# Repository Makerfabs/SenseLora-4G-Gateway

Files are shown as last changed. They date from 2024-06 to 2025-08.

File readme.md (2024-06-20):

# SenseLoRa 4G Gateway

```c++
/*
Version:		V1.0
Author:			Vincent
Create Date:	2024/6/19
Note:

*/
```
# Makerfabs

[Makerfabs home page](https://www.makerfabs.com/)

[Makerfabs Wiki](https://wiki.makerfabs.com/)

# How To Use

## Arduino Complier Option

**If you have any questions，such as how to install the development board, how to download the code, how to install the library. Please refer to :[Makerfabs_FAQ](https://github.com/Makerfabs/Makerfabs_FAQ)**

- Install board : ESP32 Version 2.0.11
- Select "ESP32-S3"
- Select Erase All Flash
- Upload codes

Arduino libraries:

- RadioLib 4.6.0

## Example

### fw_test

The factory test program detects whether the AT module can search for the operator and receives Lora data in a loop.

### at_test

Used to debug the AT module and perform transparent serial port transmission.

### lora2thingspeak

The JSON data from the SenseLora Air Monitor is parsed and forwarded to ThingSpeak.

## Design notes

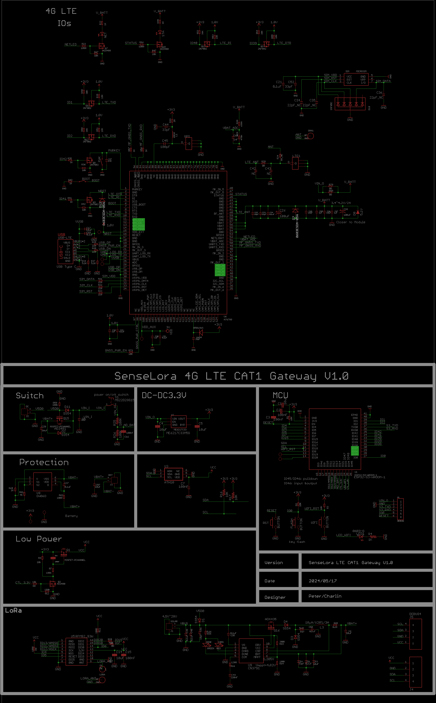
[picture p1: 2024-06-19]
hardware/SenseLora 4G Gateway.png

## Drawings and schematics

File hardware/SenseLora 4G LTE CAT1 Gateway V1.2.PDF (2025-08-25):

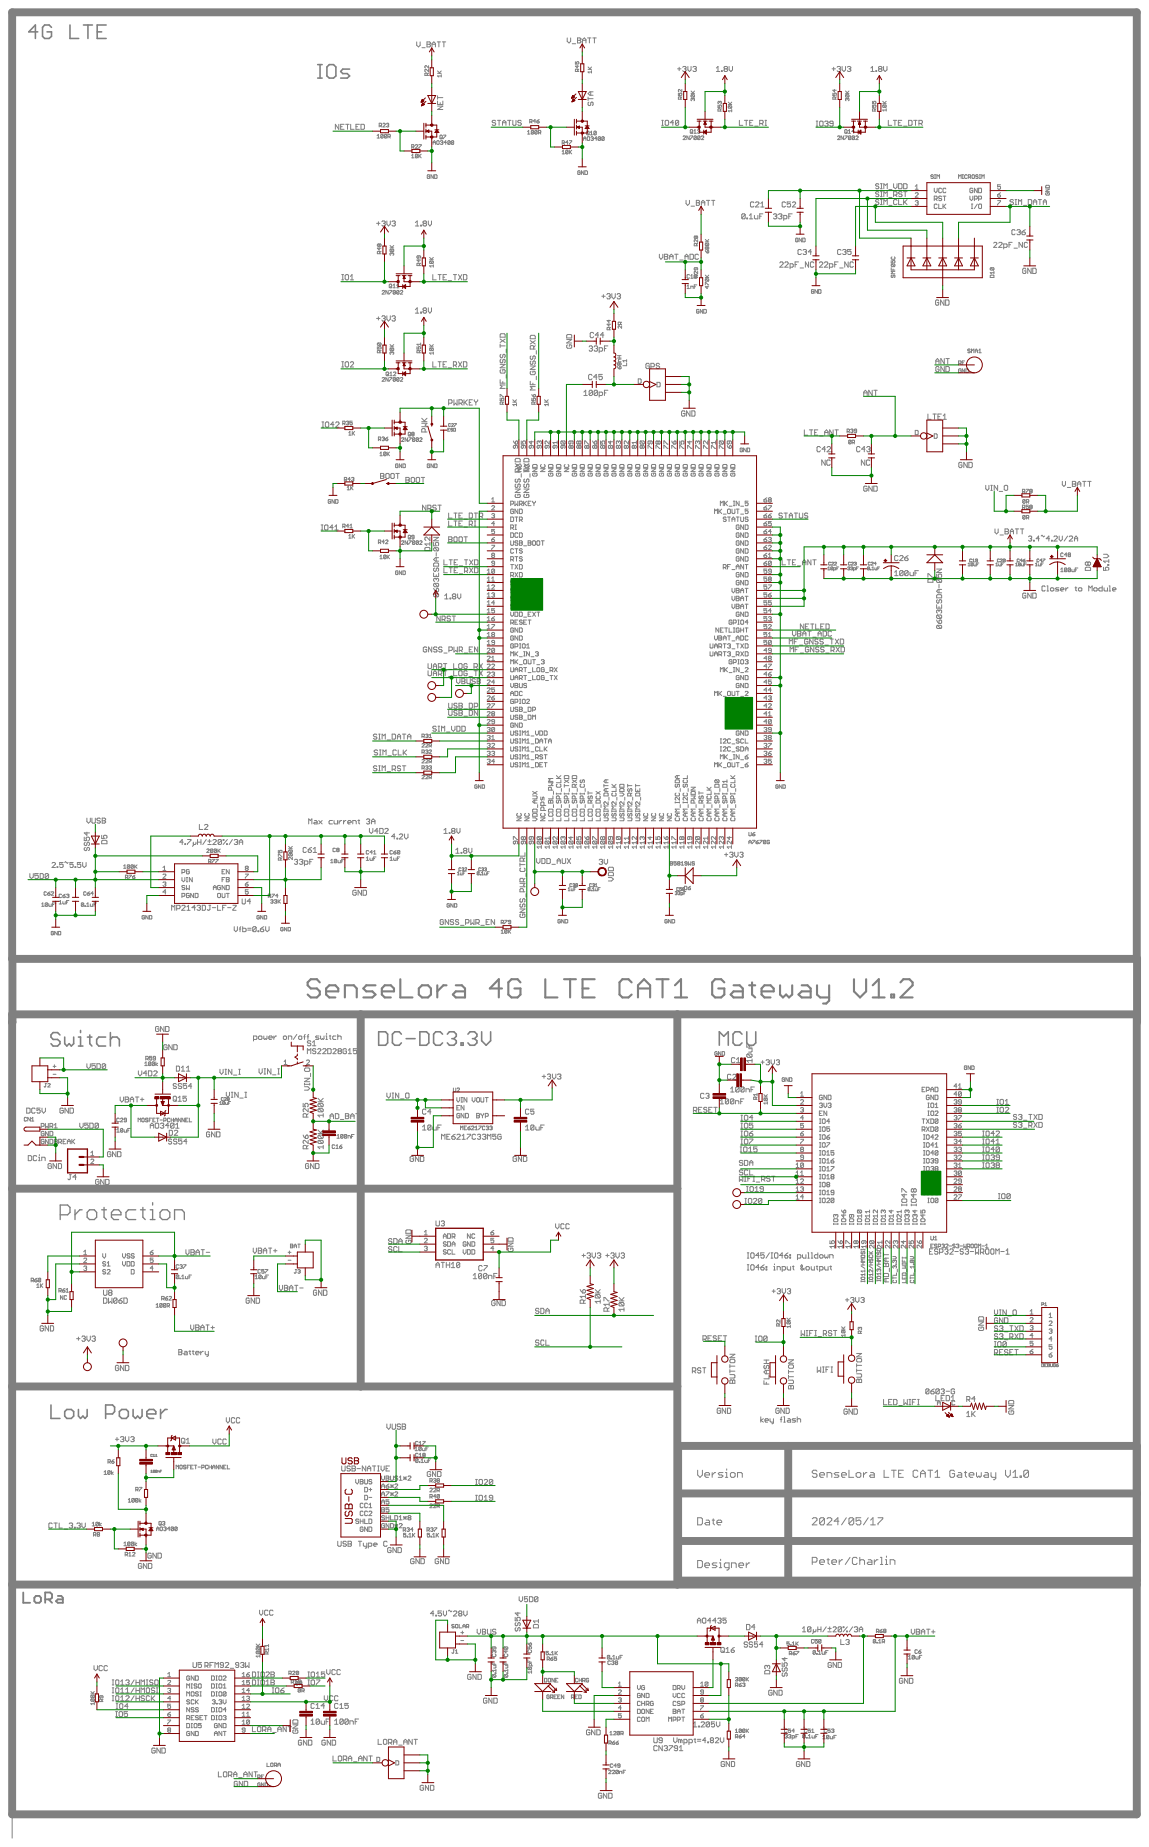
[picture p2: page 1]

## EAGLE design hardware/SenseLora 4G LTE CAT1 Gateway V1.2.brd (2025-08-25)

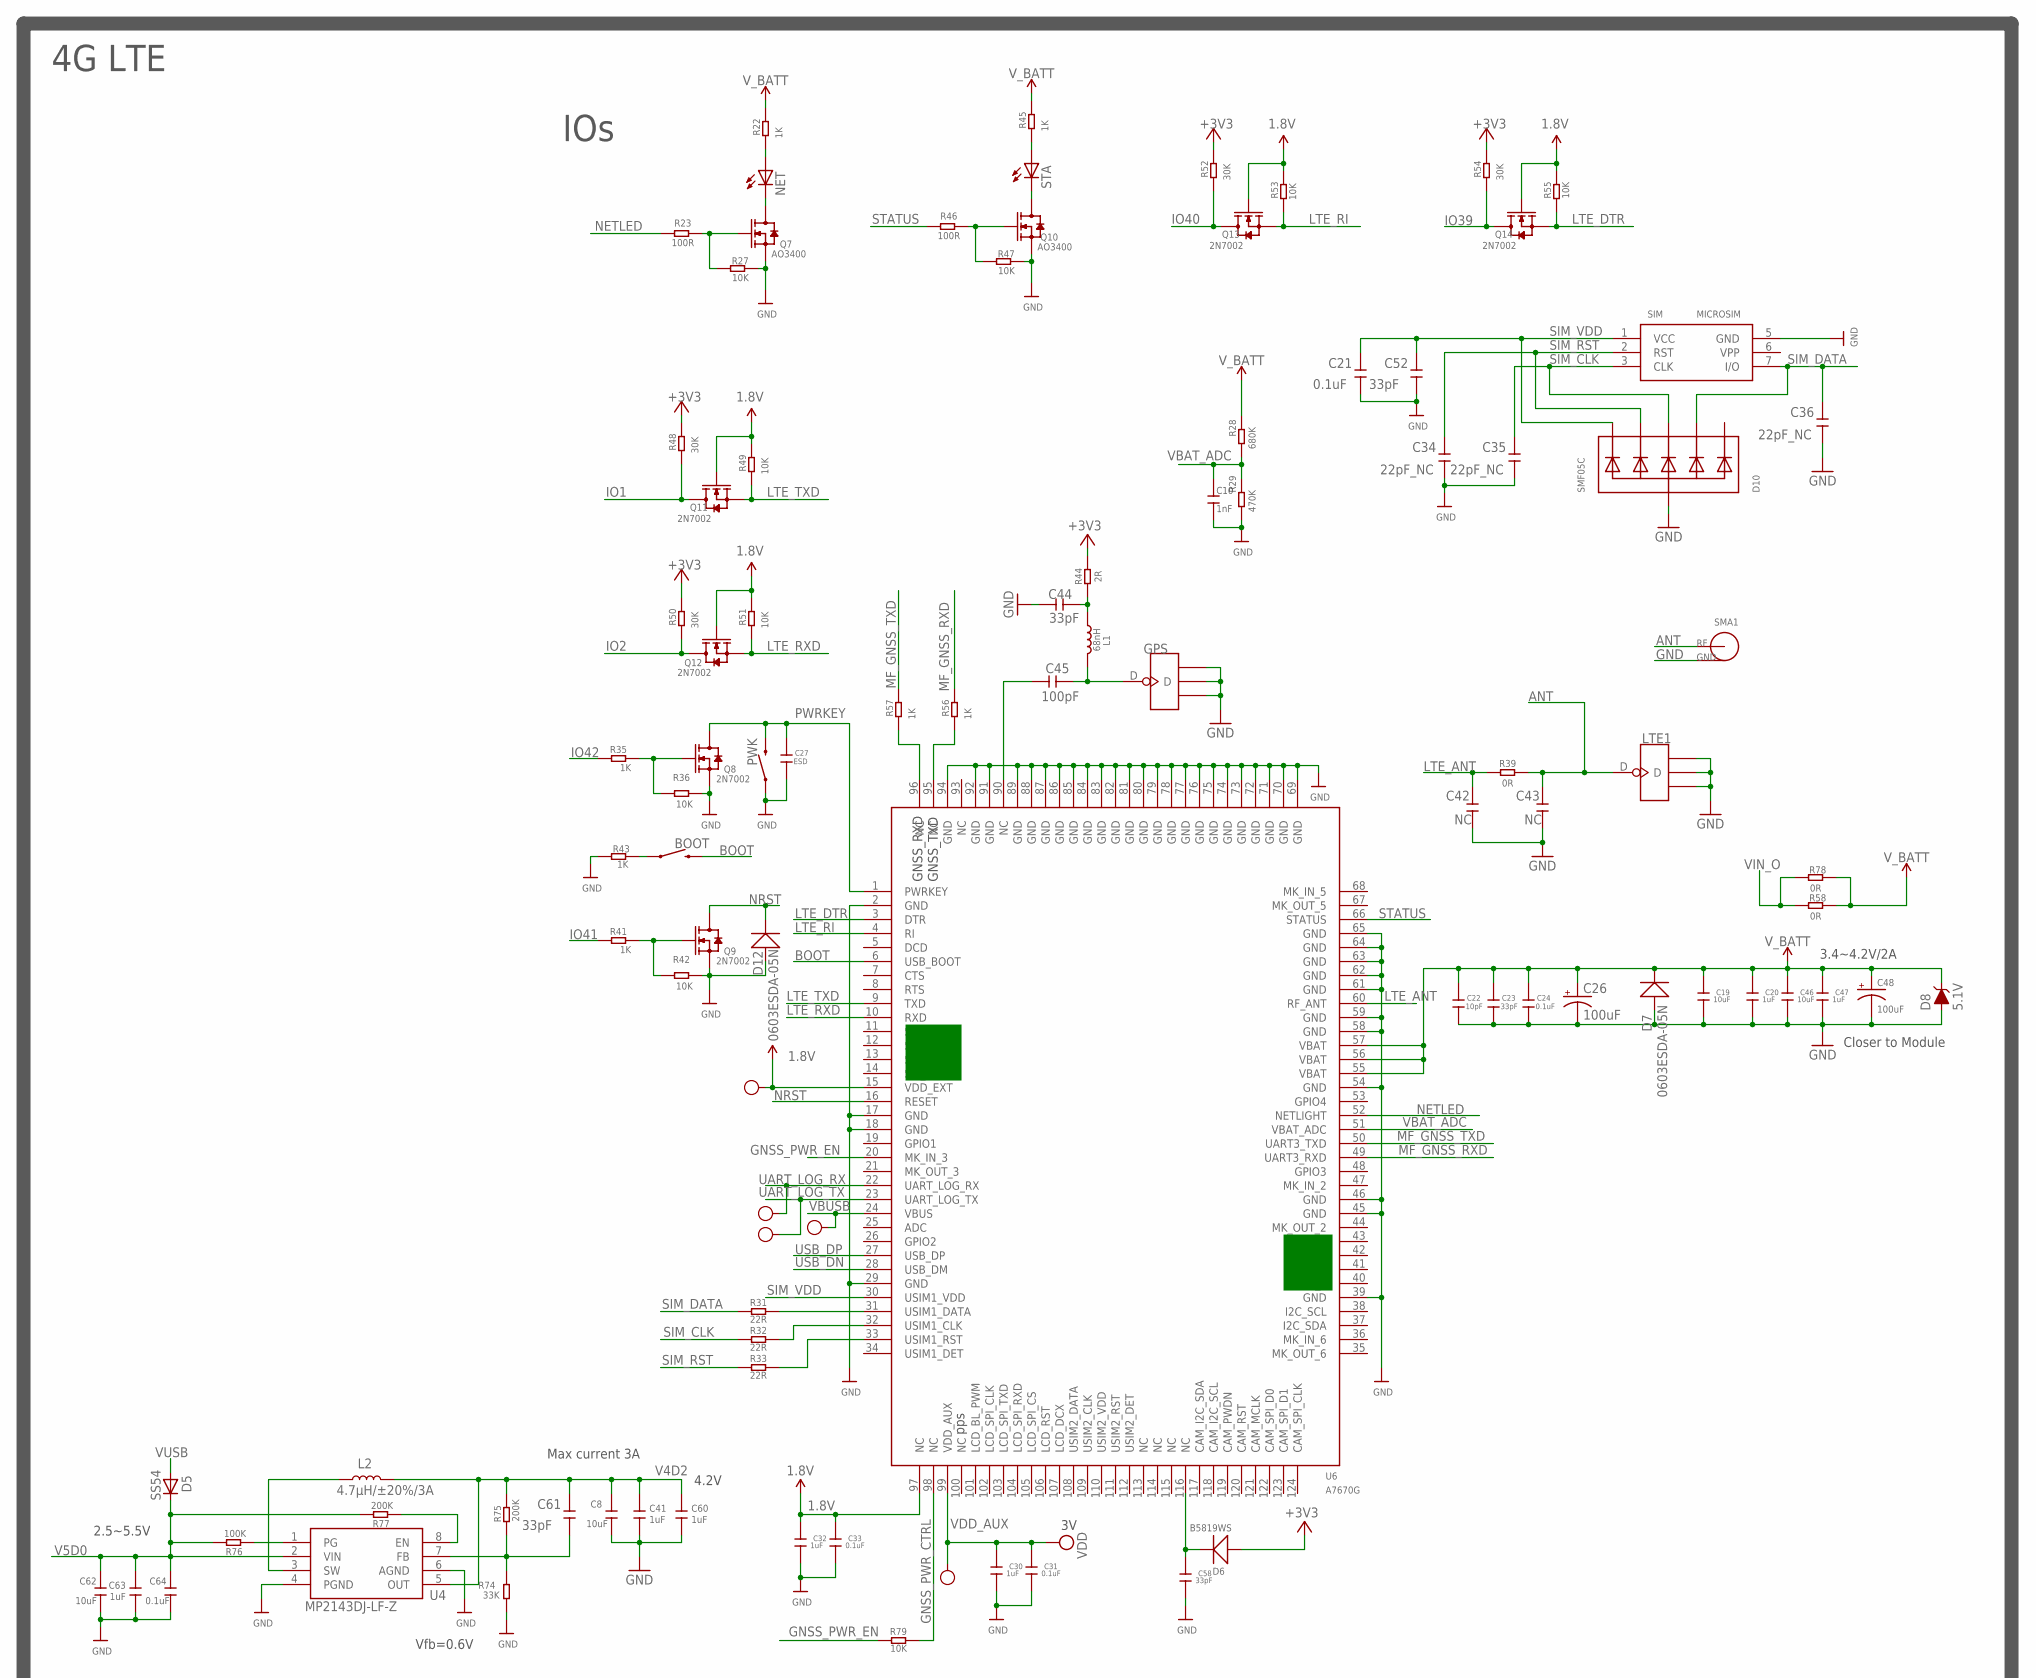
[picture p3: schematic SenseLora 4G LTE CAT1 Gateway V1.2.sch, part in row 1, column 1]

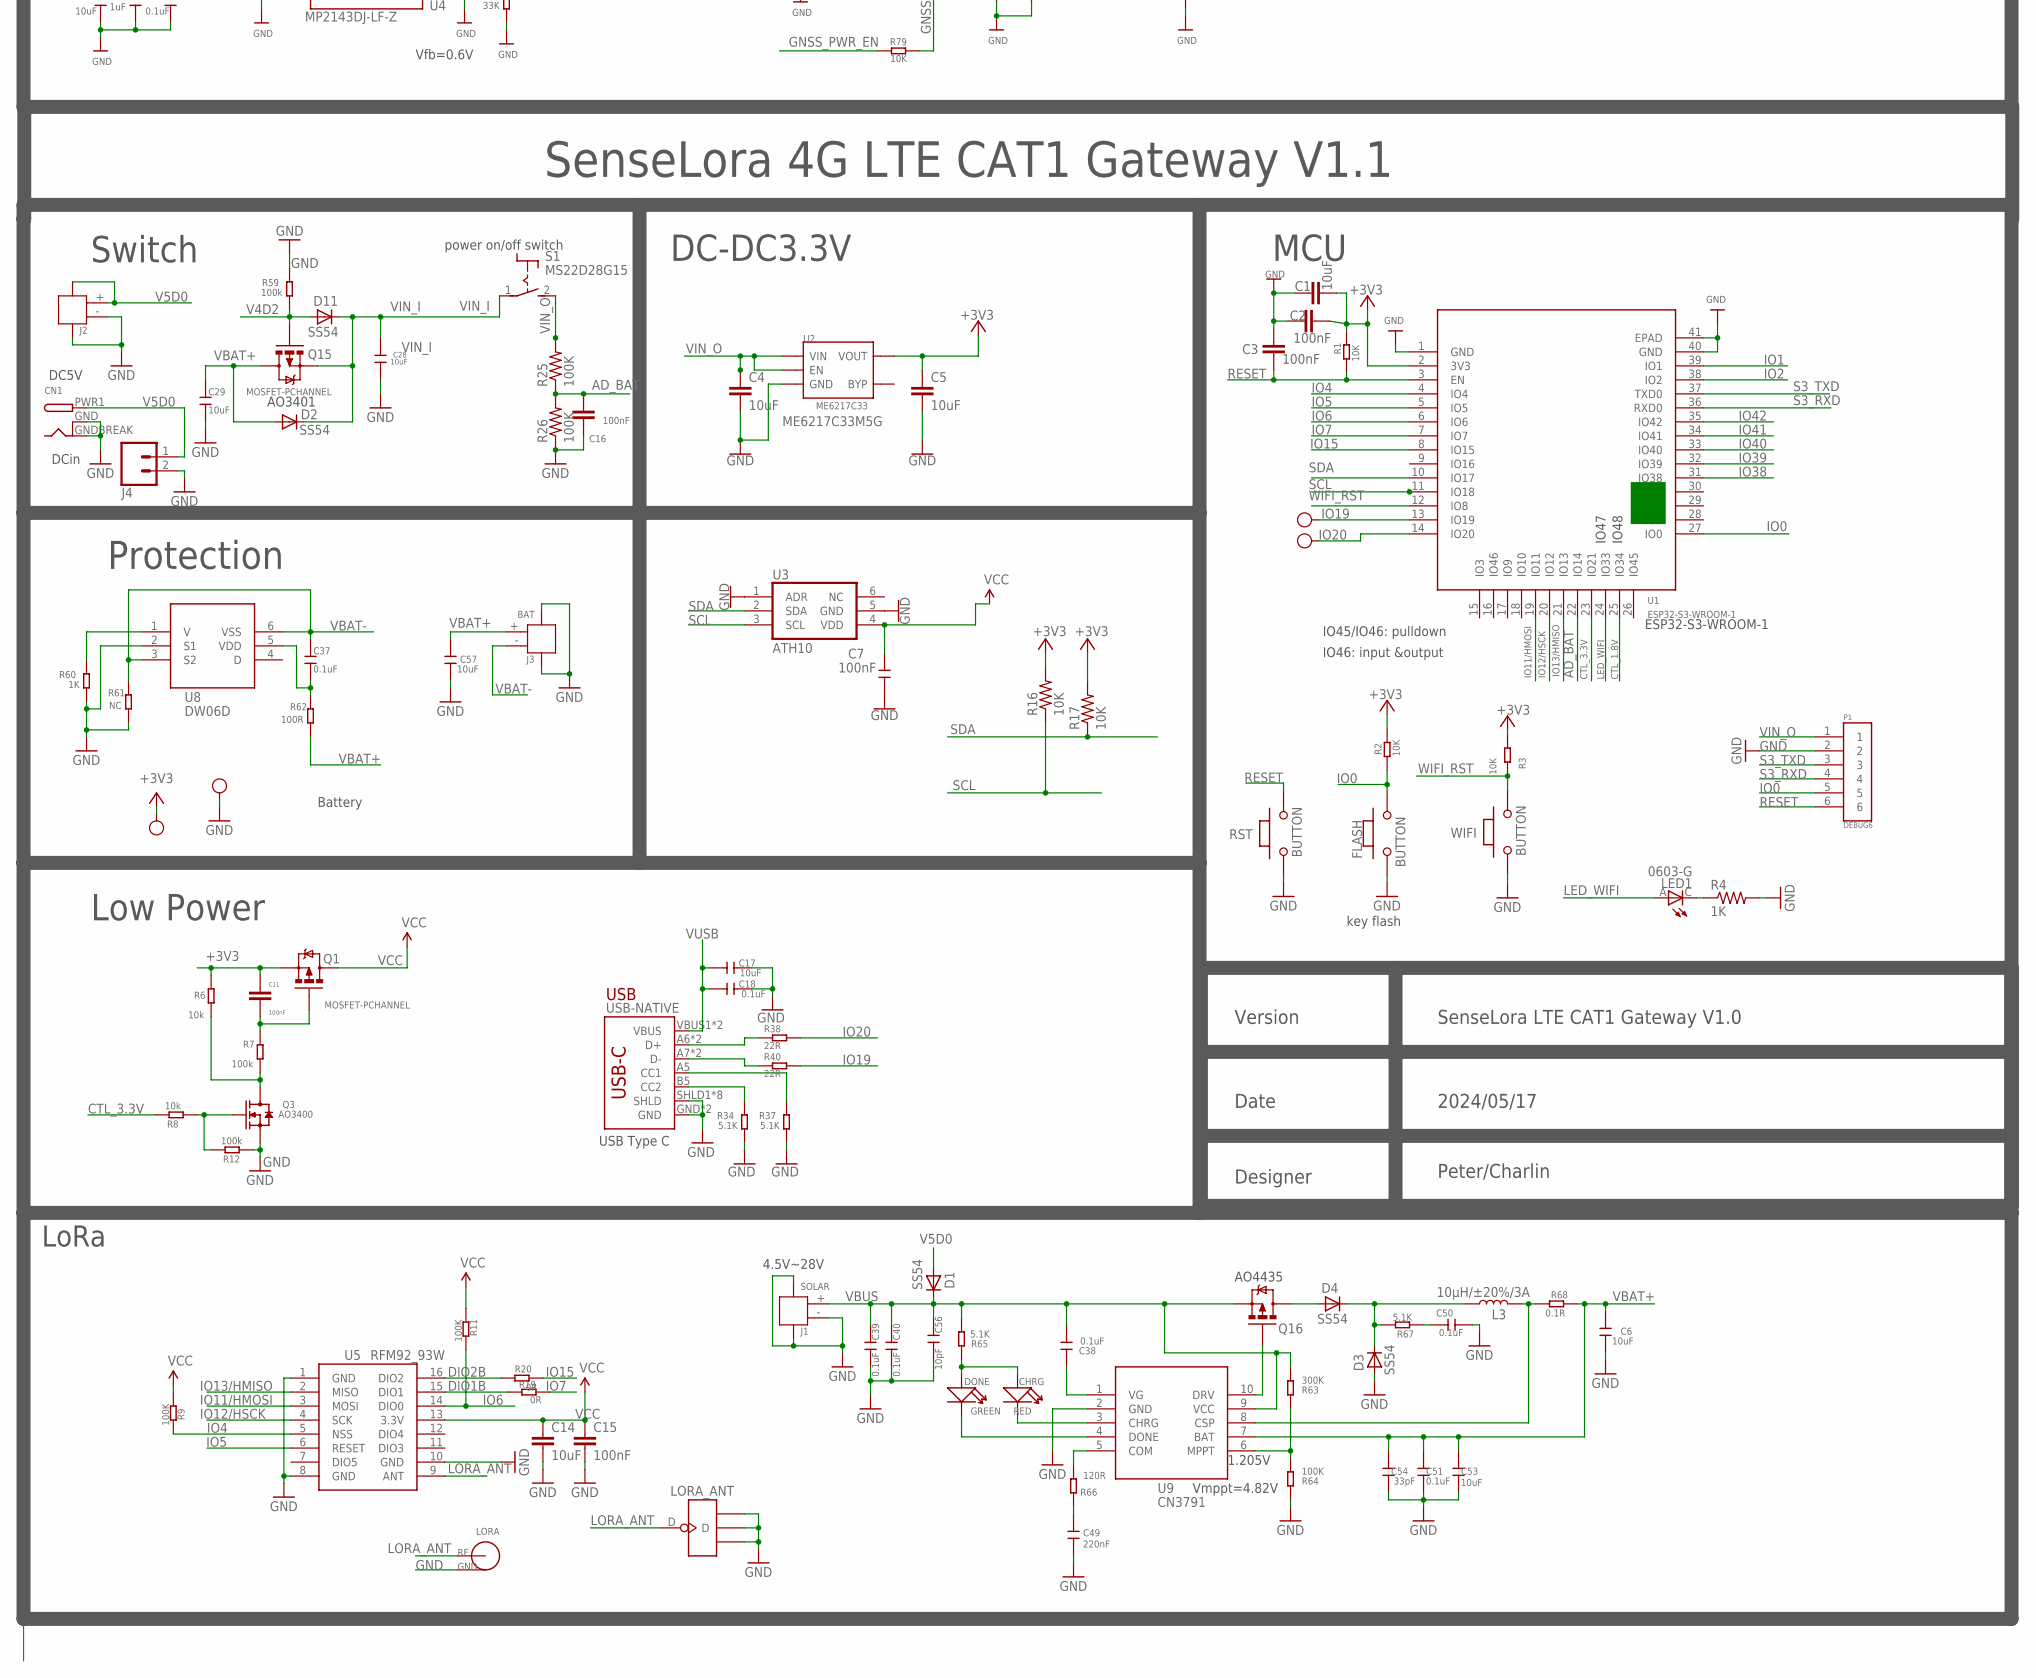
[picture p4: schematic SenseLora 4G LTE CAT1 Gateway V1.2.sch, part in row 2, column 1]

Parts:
1V8, 3V, 3V1, 3V2, 3V3: TEST-POINT'4545'; TP-D45MIL; PARTNO DNP
BOOT: MOMENTARY-SWITCH-SPST-SMD-6.0X3.5MM; TACTILE_SWITCH_SMD_6.0X3.5MM
C1, C4, C5, C14: 10uF; C0603
C2, C3, C11, C15, C16: 100nF; C0603
C6, C53, C57: 10uF; DISCRETE_C0603
C7: 100nF; 0603
C8, C17, C19, C28, C29, C46, C62: 10uF; 0603
C10: 1nF; 0603
C18, C21, C24, C31, C33, C37, C64: 0.1uF; 0603
C20, C30, C32, C41, C47, C60, C63: 1uF; 0603
C22: 10pF; 0603
C23, C44, C52, C58, C61: 33pF; 0603
C26, C48: 100uF; EIA3528
C27: ESD; 0603
C34, C35, C36: 22pF_NC; 0603
C38, C39, C40, C50, C51: 0.1uF; DISCRETE_C0603
C42, C43: NC; 0603
C45: 100pF; 0603
C49: 220nF; DISCRETE_C0603
C54: 33pF; DISCRETE_C0603
C56: 10pF; DISCRETE_C0603
CHRG: RED; LED-0603
CN1: DCBARRELSMT; DCJACK_2MM_SMT
D1, D2, D3, D4, D5, D11: SS54; DO-214AC
D6: B5819WS; SOD323
D7, D12: 0603ESDA-05N; DISCRETE_SOD523
D8: 5.1V; SOD-323
D10: SMF05C; SOT363
DONE: GREEN; LED-0603
FLASH: BUTTON; 157SW
GND: TEST-POINT'4545'; TP-D45MIL; PARTNO DNP
GPS: ANTENNA-U-FL; 4P-U-FL
J1: SOLAR; HW2-SMD-2.0-90D
J2: DC; HW2-SMD-2.0-90D
J3: BAT; HW2-SMD-2.0-90D
J4: CONN_02PTH4; 1X02_XTRA_BIG
L1: 68nH; L0603
L2: 4.7µH/±20%/3A; SRN6045
L3: 10µH/±20%/3A; SRN6045
LED1: 0603-G; LED0603
LORA: SMA-KWE
LORA_ANT: ANTENNA-U-FL; 4P-U-FL
LTE1: ANTENNA-U-FL; 4P-U-FL
NET: NET; CHIP-LED0805
P1: DEBUG6; DEBUG*6
PWK: MOMENTARY-SWITCH-SPST-SMD-6.0X3.5MM; TACTILE_SWITCH_SMD_6.0X3.5MM
Q1, Q15: MOSFET-PCHANNEL; SOT23-3
Q3, Q7, Q10: AO3400; SOT23
Q8, Q9, Q11, Q12, Q13, Q14: 2N7002; SOT23
Q16: MOSFET-PCHANNELFDS6675; SO08
R1, R2, R3, R16, R17, R27, R36, R42, R47, R49, R51, R53, R55, R79: 10K; R0603
R4, R22, R35, R41, R43, R45, R56, R57, R60: 1K; R0603
R6, R8: 10k; R0603
R7, R12, R59: 100k; R0603
R9, R11, R25, R26, R76: 100K; R0603
R19, R20, R39, R58, R78: 0R; R0603
R23, R46, R62: 100R; R0603
R28: 680K; R0603
R29: 470K; R0603
R31, R32, R33, R38, R40: 22R; R0603
R34, R37: 5.1K; R0603
R44: 2R; R0603
R48, R50, R52, R54: 30K; R0603
R61: NC; R0603
R63: 300K; DISCRETE_R0603
R64: 100K; DISCRETE_R0603
R65, R67: 5.1K; DISCRETE_R0603
R66: 120R; DISCRETE_R0603
R68: 0.1R; DISCRETE_R2512
R74: 33K; R0603
R75, R77: 200K; R0603
RST: BUTTON; 157SW
RX: TEST-POINT'4545'; TP-D45MIL; PARTNO DNP
S1: MS22D28G15; S-MS22D28G15
SIM: MICROSIM
SMA1: SMA-KWE
STA: NET; CHIP-LED0805
TX: TEST-POINT'4545'; TP-D45MIL; PARTNO DNP
U1: ESP32-S3-WROOM-1; ESP32-­S2-­SOLO
U2: ME6217C33; SOT23-5
U3: ATH10; AHT10
U4: MP2143DJ-LF-Z; TSOT23-8
U5: RFM92_93W
U6: A7670G
U8: DW06D; SOT-23-6
U9: CN3791; SSOP-10-150MIL
USB-NATIVE: USB_C5; USB-C-16P-5
VU: TEST-POINT'4545'; TP-D45MIL; PARTNO DNP
WIFI: BUTTON; 157SW

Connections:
1.8V: 1V8.T, C32.2, C33.2, Q11.1 (G), Q12.1 (G), Q13.1 (G), Q14.1 (G), R49.2, R51.2, R53.2, R55.2, U6.15 (VDD_EXT), U6.97 (NC)
+3V3: 3V3.T, C1.2, C2.2, C5.1, C11.1, D6.+, Q1.2 (S), R1.2, R2.2, R3.2, R6.2, R16.2, R17.2, R44.2, R48.2, R50.2, R52.2, R54.2, U1.2 (3V3), U2.5 (VOUT)
AD_BAT: C16.2, R25.1, R26.2, U1.22 (IO14)
ANT: C43.2, LTE1.D, R39.2, SMA1.1 (SIG)
BOOT: BOOT.2, U6.6 (USB_BOOT)
CTL_1.8V: U1.25 (IO34)
CTL_3.3V: R8.2, U1.23 (IO21)
DIO1B: R19.2, U5.15 (DIO1)
DIO2B: R20.2, U5.16 (DIO2)
GND: C1.1, C2.1, C3.2, C4.2, C5.2, C6.2, C7.1, C8.1, C10.2, C14.2, C15.2, C16.1, C17.2, C18.2, C19.1, C20.1, C21.1, C22.1, C23.1, C24.1, C26.C (-), C27.1, C28.1, C29.2, C30.1, C31.1, C32.1, C33.1, C34.1, C35.1, C36.1, C39.2, C40.2, C41.1, C42.1, C43.1, C44.2, C46.1, C47.1, C48.C (-), C49.2, C50.2, C51.2, C52.1, C53.2, C54.2, C56.2, C57.2, C58.1, C60.1, C62.1, C63.1, C64.1, CN1.GND (GNDBREAK), CN1.GNDBREAK (GND), D3.A, D7.+, D8.A, D10.2 (A), D12.+, FLASH.1, GND.T, GPS.GND1, GPS.GND2, GPS.GND3, J1.3, J1.4, J1.- (2), J2.3, J2.- (2), J3.3, J3.4, J4.2, LORA.2 (GND), LORA.3 (GND), LORA.4 (GND), LORA.5 (GND), LORA_ANT.GND1, LORA_ANT.GND2, LORA_ANT.GND3, LTE1.GND1, LTE1.GND2, LTE1.GND3, P1.2, PWK.1, Q3.2 (S), Q7.2 (S), Q8.2 (S), Q9.2 (S), Q10.2 (S), R4.2, R12.1, R26.1, R27.1, R29.1, R34.1, R36.1, R37.1, R42.1, R43.2, R47.1, R59.2, R60.1, R61.1, R64.1, R74.1, RST.1, SIM.5 (GND), SMA1.2 (GND), SMA1.3 (GND), SMA1.4 (GND), SMA1.5 (GND), U1.1 (GND), U1.40 (GND), U1.41 (EPAD), U2.2 (GND), U3.1 (ADR), U3.5 (GND), U4.4 (PGND), U4.6 (AGND), U5.1 (GND), U5.8 (GND), U5.10 (GND), U6.2 (GND), U6.17 (GND), U6.18 (GND), U6.29 (GND), U6.39 (GND), U6.45 (GND), U6.46 (GND), U6.54 (GND), U6.58 (GND), U6.59 (GND), U6.61 (GND), U6.62 (GND), U6.63 (GND), U6.64 (GND), U6.65 (GND), U6.69 (GND), U6.70 (GND), U6.71 (GND), U6.72 (GND), U6.73 (GND), U6.74 (GND), U6.75 (GND), U6.76 (GND), U6.77 (GND), U6.78 (GND), U6.79 (GND), U6.80 (GND), U6.81 (GND), U6.82 (GND), U6.83 (GND), U6.84 (GND), U6.85 (GND), U6.86 (GND), U6.87 (GND), U6.88 (GND), U6.89 (GND), U6.91 (GND), U6.92 (GND), U6.94 (GND), U8.2 (S1), U9.2 (GND), USB-NATIVE.GND, USB-NATIVE.GND2 (GND), USB-NATIVE.SHLD1 (SHLD), USB-NATIVE.SHLD2 (SHLD), USB-NATIVE.SHLD3 (SHLD), USB-NATIVE.SHLD4 (SHLD), USB-NATIVE.SHLD5 (SHLD), USB-NATIVE.SHLD6 (SHLD), USB-NATIVE.SHLD7 (SHLD), USB-NATIVE.SHLD8 (SHLD), WIFI.1
GNSS_PWR_CTRL: R79.1, U6.98 (NC)
GNSS_PWR_EN: R79.2, U6.20 (MK_IN_3)
IO0: FLASH.2, P1.5, R2.1, U1.27 (IO0)
IO1: Q11.3 (D), R48.1, U1.39 (IO1)
IO2: Q12.3 (D), R50.1, U1.38 (IO2)
IO4: R9.1, U1.4 (IO4), U5.5 (NSS)
IO5: U1.5 (IO5), U5.6 (RESET)
IO6: R11.1, U1.6 (IO6), U5.14 (DIO0)
IO7: R19.1, U1.7 (IO7)
IO11/HMOSI: U1.19 (IO11), U5.3 (MOSI)
IO12/HSCK: U1.20 (IO12), U5.4 (SCK)
IO13/HMISO: U1.21 (IO13), U5.2 (MISO)
IO15: R20.1, U1.8 (IO15)
IO19: 3V1.T, R40.1, U1.13 (IO19)
IO20: 3V2.T, R38.1, U1.14 (IO20)
IO38: U1.31 (IO38)
IO39: Q14.3 (D), R54.1, U1.32 (IO39)
IO40: Q13.3 (D), R52.1, U1.33 (IO40)
IO41: R41.2, U1.34 (IO41)
IO42: R35.2, U1.35 (IO42)
LED_WIFI: LED1.A, U1.24 (IO33)
LORA_ANT: LORA.1 (SIG), LORA_ANT.D, U5.9 (ANT)
LTE_ANT: C42.2, R39.1, U6.60 (RF_ANT)
LTE_DTR: Q14.2 (S), R55.1, U6.3 (DTR)
LTE_RI: Q13.2 (S), R53.1, U6.4 (RI)
LTE_RXD: Q12.2 (S), R51.1, U6.10 (RXD)
LTE_TXD: Q11.2 (S), R49.1, U6.9 (TXD)
MF_GNSS_RXD: R56.2, U6.49 (UART3_RXD)
MF_GNSS_TXD: R57.2, U6.50 (UART3_TXD)
unnamed: LED1.C, R4.1
unnamed: Q7.1 (G), R23.1, R27.2
unnamed: NET.C, Q7.3 (D)
unnamed: NET.A, R22.1
unnamed: Q16.4 (G), U9.10 (DRV)
unnamed: BOOT.1, R43.1
unnamed: Q10.1 (G), R46.1, R47.2
unnamed: C37.2, R62.2, U8.5 (VDD)
unnamed: C11.2, Q1.1 (G), R7.2
unnamed: Q3.1 (G), R8.1, R12.2
unnamed: R60.2, U8.1 (V)
unnamed: R63.1, R64.2, U9.6 (MPPT)
unnamed: Q3.3 (D), R6.1, R7.1
unnamed: C58.2, D6.-, U6.116 (NC)
unnamed: C38.2, U9.1 (VG)
unnamed: CHRG.+, DONE.+, R65.1
unnamed: R31.1, U6.31 (USIM1_DATA)
unnamed: R32.1, U6.32 (USIM1_CLK)
unnamed: R33.1, U6.33 (USIM1_RST)
unnamed: CHRG.-, U9.3 (CHRG)
unnamed: L2.1, U4.3 (SW)
unnamed: R37.2, USB-NATIVE.A5 (CC1)
unnamed: R34.2, USB-NATIVE.B5 (CC2)
unnamed: R45.1, STA.A
unnamed: Q10.3 (D), STA.C
unnamed: R38.2, USB-NATIVE.A6 (D+), USB-NATIVE.B6 (D+)
unnamed: R40.2, USB-NATIVE.A7 (D-), USB-NATIVE.B7 (D-)
unnamed: Q9.1 (G), R41.1, R42.2
unnamed: C45.2, U6.90 (NC)
unnamed: DONE.-, U9.4 (DONE)
unnamed: R56.1, U6.95 (NC)
unnamed: R57.1, U6.96 (NC)
unnamed: C61.1, R74.2, R75.1, U4.7 (FB)
unnamed: R76.1, U4.1 (PG)
unnamed: R66.2, U9.5 (COM)
unnamed: C49.1, R66.1
unnamed: Q8.1 (G), R35.1, R36.2
unnamed: D4.A, Q16.5 (D), Q16.6 (D), Q16.7 (D), Q16.8 (D)
unnamed: D3.C, D4.C, L3.1, R67.2
unnamed: L3.2, R68.1, U9.8 (CSP)
unnamed: C50.1, R67.1
unnamed: R77.1, U4.8 (EN)
unnamed: C44.1, L1.1, R44.1
unnamed: C45.1, GPS.D, L1.2
NETLED: R23.2, U6.52 (NETLIGHT)
NRST: D12.-, Q9.3 (D), U6.16 (RESET)
PWRKEY: C27.2, PWK.2, Q8.3 (D), U6.1 (PWRKEY)
RESET: C3.1, P1.6, R1.1, RST.2, U1.3 (EN)
S3_RXD: P1.4, U1.36 (RXD0)
S3_TXD: P1.3, U1.37 (TXD0)
SCL: R16.1, U1.11 (IO18), U3.3 (SCL)
SDA: R17.1, U1.10 (IO17), U3.2 (SDA)
SIM_CLK: C35.2, D10.4 (C3), R32.2, SIM.3 (CLK)
SIM_DATA: C36.2, D10.3 (C2), R31.2, SIM.7 (I/O)
SIM_RST: C34.2, D10.5 (C4), R33.2, SIM.2 (RST)
SIM_VDD: C21.2, C52.2, D10.6 (C5), SIM.1 (VCC), U6.30 (USIM1_VDD)
STATUS: R46.2, U6.66 (STATUS)
UART_LOG_RX: RX.T, U6.22 (UART_LOG_RX)
UART_LOG_TX: TX.T, U6.23 (UART_LOG_TX)
USB_DN: U6.28 (USB_DM)
USB_DP: U6.27 (USB_DP)
V4D2: C8.2, C41.2, C60.2, C61.2, D11.A, L2.2, Q15.1 (G), R59.1, R75.2, U4.5 (OUT)
V5D0: C62.2, C63.2, C64.2, CN1.PWR1 (PWR), D1.A, D5.C, J2.4, J2.+ (1), J4.1, R76.2, R77.2, U4.2 (VIN)
VBAT+: C6.1, C29.1, C51.1, C53.1, C54.1, C57.1, D2.A, J3.+ (1), Q15.3 (D), R62.1, R68.2, U9.7 (BAT)
VBAT-: C37.1, J3.- (2), R61.2, U8.3 (S2), U8.6 (VSS)
VBAT_ADC: C10.1, R28.1, R29.2, U6.51 (VBAT_ADC)
VBUS: C38.1, C39.1, C40.1, C56.1, D1.C, J1.+ (1), Q16.1 (S), Q16.2 (S), Q16.3 (S), R63.2, R65.2, U9.9 (VCC)
VBUSB: U6.24 (VBUS), VU.T
VCC: C7.2, C14.1, C15.1, Q1.3 (D), R9.2, R11.2, U3.4 (VDD), U5.13 (3.3V)
VDD_AUX: 3V.T, C30.2, C31.2, U6.99 (VDD_AUX)
VIN_I: C28.2, D2.C, D11.C, Q15.2 (S), S1.1
VIN_O: C4.1, P1.1, R25.2, R58.2, R78.2, S1.2 (S), U2.1 (VIN), U2.3 (EN)
VUSB: C17.1, C18.1, D5.A, USB-NATIVE.VBUS1 (VBUS), USB-NATIVE.VBUS2 (VBUS)
V_BATT: C19.2, C20.2, C22.2, C23.2, C24.2, C26.A (+), C46.2, C47.2, C48.A (+), D7.-, D8.C, R22.2, R28.2, R45.2, R58.1, R78.1, U6.55 (VBAT), U6.56 (VBAT), U6.57 (VBAT)
WIFI_RST: R3.1, U1.12 (IO8), WIFI.2

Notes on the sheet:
DC-DC3.3V
ME6217C33M5G
LoRa
power on/off switch
key flash
Switch
MCU
Low Power
IO45/IO46: pulldown
IO46: input &output
ESP32-S3-WROOM-1
IO47
IO48
SenseLora 4G LTE CAT1 Gateway V1.1
Version
Date
Designer
SenseLora LTE CAT1 Gateway V1.0
2024/05/17
Peter/Charlin
IOs
USB
USB Type C
Closer to Module
3.4~4.2V/2A
GNSS_TXD
GNSS_RXD
4G LTE
pps
AO3401
Battery
Protection
4.5V~28V
1.205V
Vmppt=4.82V
AO4435
4.2V
Max current 3A
Vfb=0.6V
2.5~5.5V

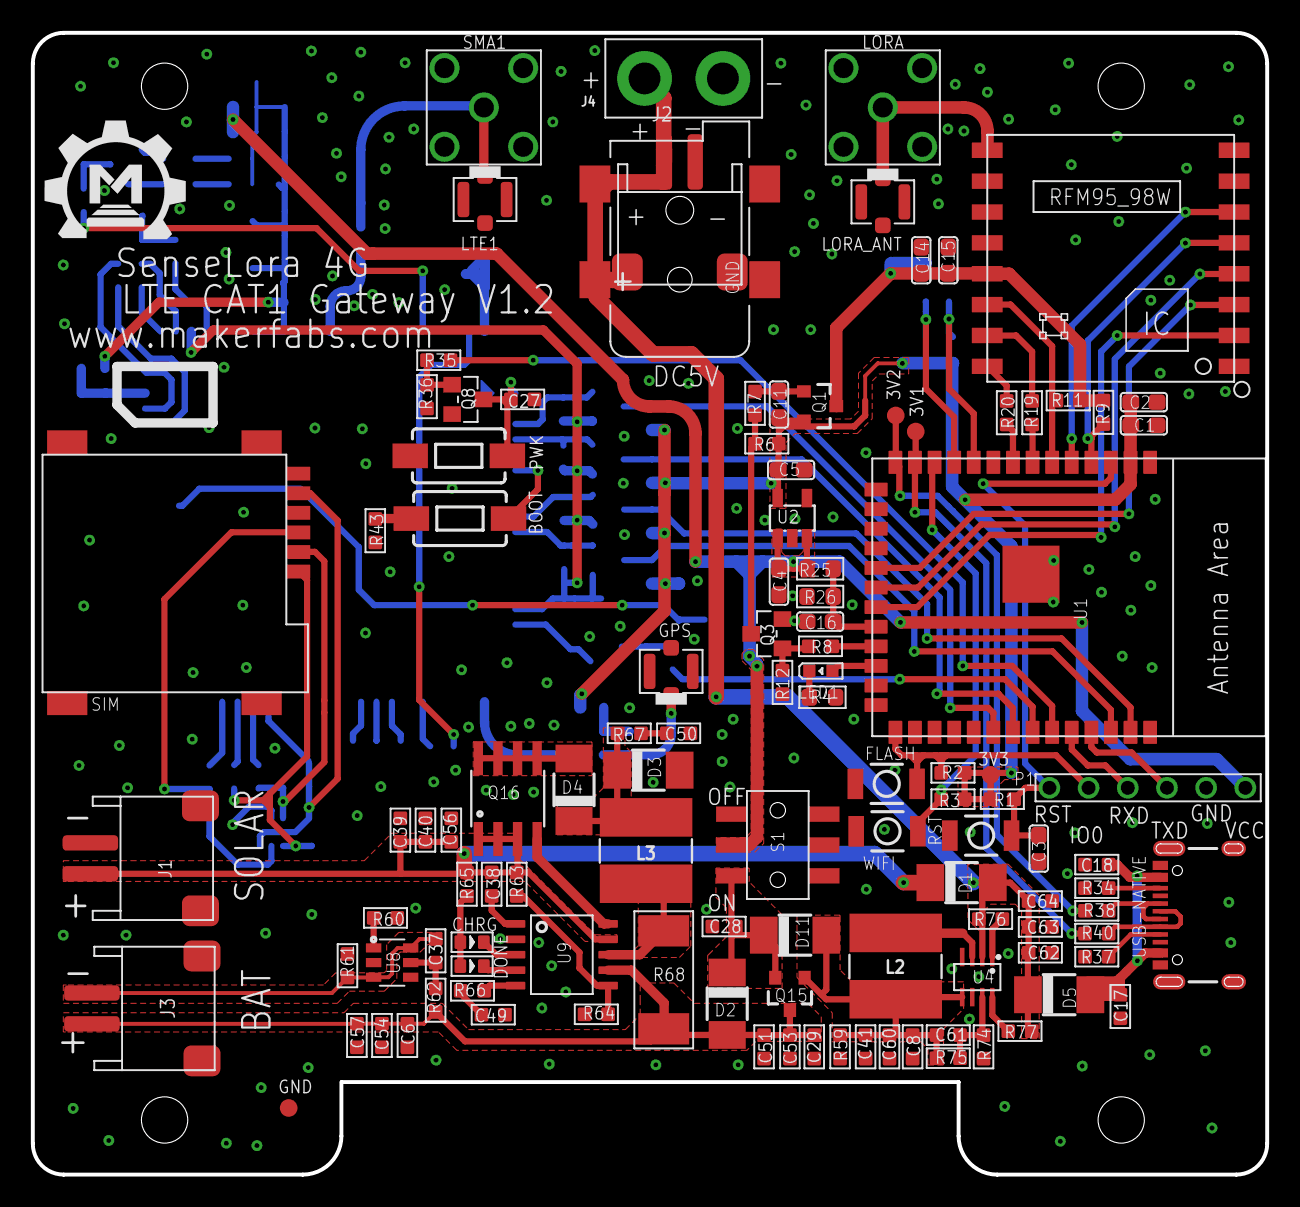
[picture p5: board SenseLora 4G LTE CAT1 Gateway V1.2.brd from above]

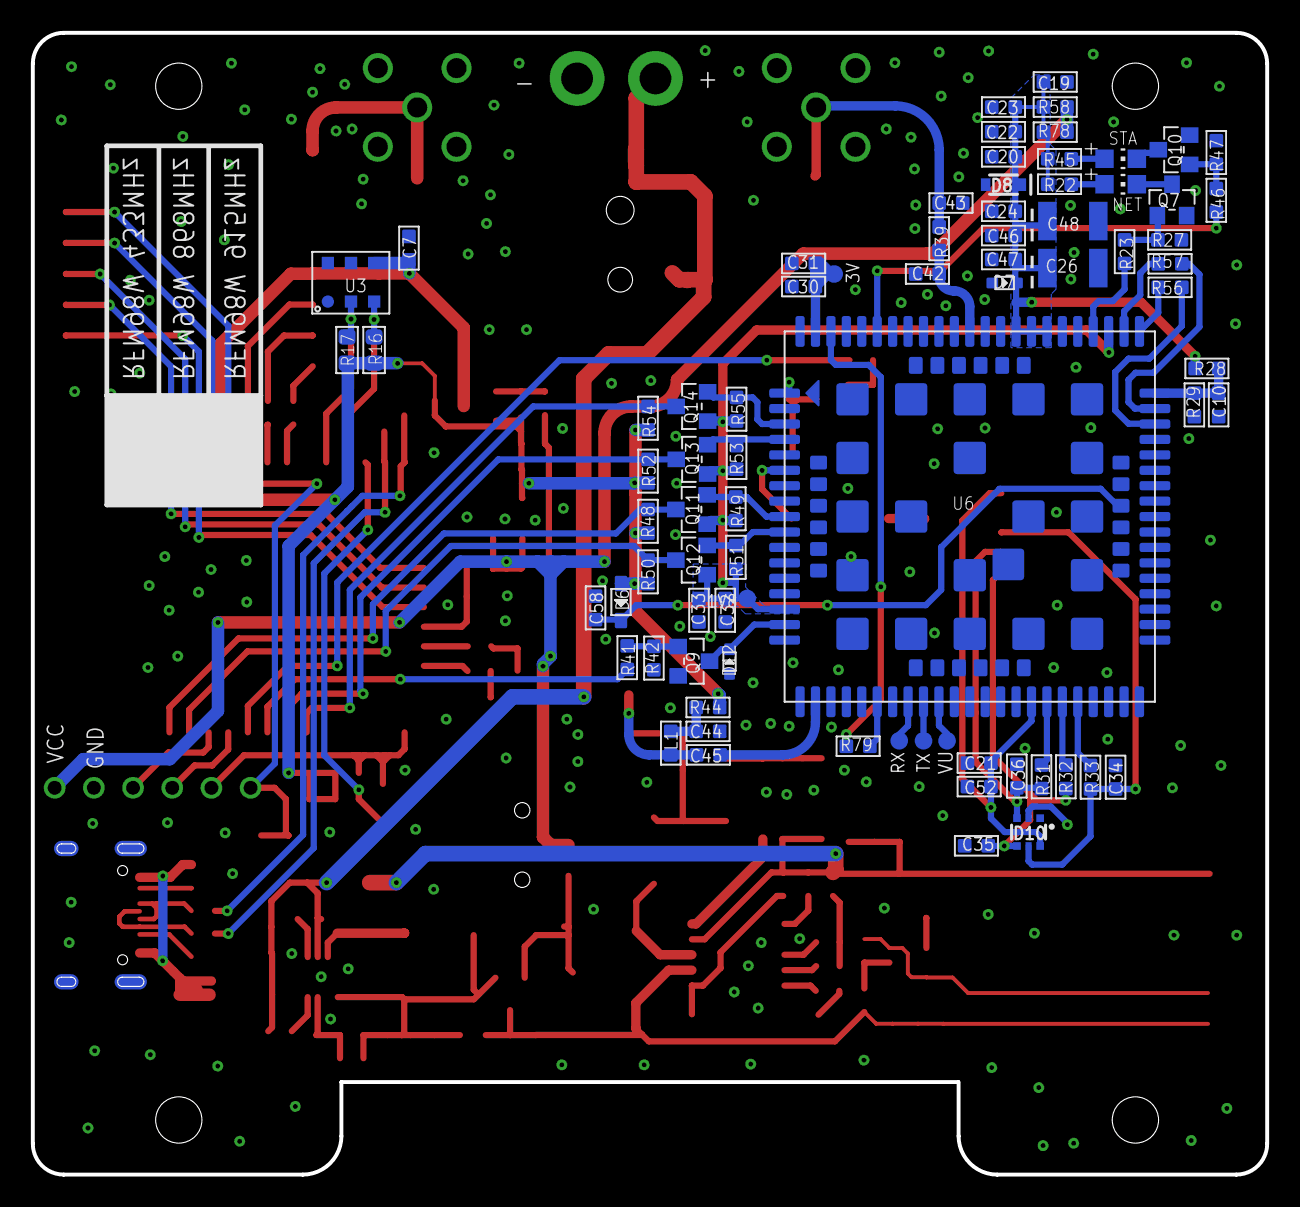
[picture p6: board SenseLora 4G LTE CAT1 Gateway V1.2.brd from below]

Board: 2 copper layers, 80.0 x 74.0 mm, 191 parts (77 on the bottom side), 110 nets.

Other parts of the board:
U$2: MAKERFABS_0.3

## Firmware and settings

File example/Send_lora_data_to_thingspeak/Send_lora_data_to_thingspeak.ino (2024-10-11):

// 使用 4.6.0  版本的库 RadioLib 在文件夹： C:\Users\maker\Documents\Arduino\libraries\RadioLib 
// 使用 2.0.0  版本的库 SPI 在文件夹： C:\Users\maker\AppData\Local\Arduino15\packages\esp32\hardware\esp32\2.0.15\libraries\SPI 
// 使用 7.0.4  版本的库 ArduinoJson 在文件夹： C:\Users\maker\Documents\Arduino\libraries\ArduinoJson 

#include <Arduino.h>
#include <RadioLib.h>
#include <SPI.h>
#include <ArduinoJson.h>

// 4G
#define BAT_PIN 14
#define IO_RXD2 1
#define IO_TXD2 2
#define IO_GSM_PWRKEY 42
#define IO_GSM_RST 41
#define POWER_3V3_PIN 21

// LoRa
#define LORA_MOSI 11
#define LORA_MISO 13
#define LORA_SCK 12
#define LORA_CS 4

#define LORA_RST 5
#define LORA_DIO0 6
#define LORA_DIO1 7

#define FREQUENCY 868
#define BANDWIDTH 125.0
#define SPREADING_FACTOR 12
#define CODING_RATE 6
#define OUTPUT_POWER 20
#define PREAMBLE_LEN 8
#define GAIN 0

#define THINGSPEAK_APIKEY "YOUR_KEY"

HardwareSerial mySerial2(2);
SX1276 radio = new Module(LORA_CS, LORA_DIO0, LORA_RST, LORA_DIO1, SPI, SPISettings());
int count = 0;

void setup()
{

    USBSerial.begin(115200);
    mySerial2.begin(115200, SERIAL_8N1, IO_RXD2, IO_TXD2);
    SPI.begin(LORA_SCK, LORA_MISO, LORA_MOSI);

    pin_init();
    lora_init();
    at_init();

    while (0)
    {
        String str = "{\"temp\":25.64,\"humi\":47.72}";
        char url[200];
        json2url(str, url);
        USBSerial.println(url);
        delay(3000);
    }
}

long runtime = 0;

void loop()
{
    lora_receive_task();
    // http_request();
}

void pin_init()
{
    USBSerial.println(F("void pin_init()"));

    pinMode(BAT_PIN, INPUT);
    pinMode(IO_GSM_RST, OUTPUT);
    pinMode(IO_GSM_PWRKEY, OUTPUT);
    pinMode(POWER_3V3_PIN, OUTPUT);

    digitalWrite(POWER_3V3_PIN, HIGH);
    digitalWrite(IO_GSM_RST, HIGH);
    delay(1000);
    digitalWrite(IO_GSM_RST, LOW);
    delay(500);
    digitalWrite(IO_GSM_PWRKEY, HIGH);
    delay(1000);
    digitalWrite(IO_GSM_PWRKEY, LOW);
}

void lora_init()
{
    USBSerial.println(F("void lora_init()"));

    int state = radio.begin(FREQUENCY, BANDWIDTH, SPREADING_FACTOR, CODING_RATE, SX127X_SYNC_WORD, OUTPUT_POWER, PREAMBLE_LEN, GAIN);
    if (state == ERR_NONE)
    {
        USBSerial.println(F("success!"));
    }
    else
    {
        USBSerial.print(F("failed, code "));
        USBSerial.println(state);
        while (true)
            ;
    }
}

void at_init()
{
    USBSerial.println(F("void at_init()"));

    sendData("AT", 1000);
    delay(1000);
    sendData("AT+SIMCOMATI", 1000);
    delay(1000);
    sendData("AT+CICCID", 1000);
    sendData("AT+CNUM", 1000);
    sendData("AT+COPS?", 1000);
    sendData("AT+CPSI?", 1000);
    sendData("AT+CSQ", 1000);
}

void http_request()
{
    // Http test
    sendData("AT+HTTPINIT", 1000);
    // sendData("AT+HTTPPARA=\"URL\",\"http://www.baidu.com\"", 1000);
    sendData("AT+HTTPPARA=\"URL\",\"http://api.thingspeak.com/update?api_key=5WOQ0JZURMWBTRF4&field1=123&field2=456\"", 1000);
    sendData("AT+HTTPACTION=0", 1000);
    sendData("AT+HTTPHEAD", 1000);
    sendData("AT+HTTPREAD=0,500", 1000);
    sendData("AT+HTTPTERM", 1000);
}

String sendData(String command, const int timeout)
{
    String response = "";
    mySerial2.println(command);
    long int time = millis();
    while ((time + timeout) > millis())
    {
        while (mySerial2.available())
        {
            char c = mySerial2.read();
            response += c;
        }
    }

    USBSerial.print(response);

    return response;
}

void lora_receive_task()
{
    // test LoRa
    String str;
    int state = radio.receive(str);

    if (state == ERR_NONE)
    {
        // packet was successfully received
        USBSerial.println(F("success!"));

        // print the data of the packet
        USBSerial.print(F("[SX1276] Data:\t\t\t"));
        USBSerial.println(str);

        // print the RSSI (Received Signal Strength Indicator)
        // of the last received packet
        USBSerial.print(F("[SX1276] RSSI:\t\t\t"));
        USBSerial.print(radio.getRSSI());
        USBSerial.println(F(" dBm"));

        // print the SNR (Signal-to-Noise Ratio)
        // of the last received packet
        USBSerial.print(F("[SX1276] SNR:\t\t\t"));
        USBSerial.print(radio.getSNR());
        USBSerial.println(F(" dB"));

        // print frequency error
        // of the last received packet
        USBSerial.print(F("[SX1276] Frequency error:\t"));
        USBSerial.print(radio.getFrequencyError());
        USBSerial.println(F(" Hz"));

        char url[200];
        json2url(str, url);
        sendData("AT+HTTPINIT", 1000);
        sendData(url, 1000);
        sendData("AT+HTTPACTION=0", 1000);
        sendData("AT+HTTPHEAD", 1000);
        sendData("AT+HTTPREAD=0,500", 1000);
        sendData("AT+HTTPTERM", 1000);
    }
    else if (state == ERR_RX_TIMEOUT)
    {
        // timeout occurred while waiting for a packet
        // Serial.println(F("timeout!"));
    }
    else if (state == ERR_CRC_MISMATCH)
    {
        // packet was received, but is malformed
        USBSerial.println(F("CRC error!"));
    }
    else
    {
        // some other error occurred
        USBSerial.print(F("failed, code "));
        USBSerial.println(state);
    }
}

// SenseLora Air Monitor
// {"ID":"AirM01","COUNT":16,"SLEEP":3600,"bat":3.97,"temp":25.64,"humi":47.72,"eco2":400.00,"lux":109.17}
// Senselora soil Monitor
// {"ID":"SoilM01","COUNT":16,"SLEEP":3600,"bat":3.97,"temp":25.64,"humi":47.72,"PH":4.00}
void json2url(String input, char *url)
{
    JsonDocument doc;
    deserializeJson(doc, input);

    float temp = doc["temp"];
    float humi = doc["humi"];
    sprintf(url, "AT+HTTPPARA=\"URL\",\"http://api.thingspeak.com/update?api_key=%s&field1=%.1f&field2=%.1f\"",THINGSPEAK_APIKEY, temp, humi);
}

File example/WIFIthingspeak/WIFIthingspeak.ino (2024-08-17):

#include <Arduino.h>
#include <Adafruit_AHT10.h>
#include <Wire.h>
#include "WiFi.h"

const char* ssid     = "9"; // Change this to your WiFi SSID
const char* password = "12345678"; // Change this to your WiFi password

const char* host = "api.thingspeak.com"; // This should not be changed
const int httpPort = 80; // This should not be changed
const String writeApiKey = "N9IBFTBI3J36T779"; // Change this to your Write API key

// 4G
#define BAT_PIN 14
#define IO_RXD2 1
#define IO_TXD2 2
#define IO_GSM_PWRKEY 42
#define IO_GSM_RST 41
#define POWER_3V3_PIN 21

//AHT10
#define SDA 17
#define SCL 18

Adafruit_AHT10 aht;

float temperature = 0.0;
float humidity = 0.0;

void setup()
{
    USBSerial.begin(115200);  
    pin_init();
    aht10_init();
    WiFi.begin(ssid, password); //connect WIFI

    while (WiFi.status() != WL_CONNECTED) //wait for connect success
    {
      delay(500);
      USBSerial.print(".");
    }
    USBSerial.println("WiFi connected!");

    USBSerial.println("IP address: ");
    USBSerial.println(WiFi.localIP()); //print IP address
}

void loop()
{    
    WiFiClient client;
    String footer = String(" HTTP/1.1\r\n") + "Host: " + String(host) + "\r\n" + "Connection: close\r\n\r\n";
    read_aht10();
    // WRITE --------------------------------------------------------------------------------------------
    if (!client.connect(host, httpPort)) {
      return;
    }
    client.print("GET /update?api_key=" + writeApiKey + "&field1=" + temperature + "&field2=" + humidity + footer);
    readResponse(&client);
    delay(10000);
}

void pin_init()
{
    USBSerial.println(F("void pin_init()"));

    pinMode(BAT_PIN, INPUT);
    pinMode(IO_GSM_RST, OUTPUT);
    pinMode(IO_GSM_PWRKEY, OUTPUT);
    pinMode(POWER_3V3_PIN, OUTPUT);

    digitalWrite(POWER_3V3_PIN, HIGH);
    digitalWrite(IO_GSM_RST, HIGH);
    delay(1000);
    digitalWrite(IO_GSM_RST, LOW);
    delay(500);
    digitalWrite(IO_GSM_PWRKEY, HIGH);
    delay(1000);
    digitalWrite(IO_GSM_PWRKEY, LOW);
}

void aht10_init()
{
    Wire.begin(SDA, SCL);
    if (!aht.begin())
        USBSerial.println("AHT10 not found.");
    else
        read_aht10();
}

void read_aht10()
{
    sensors_event_t humi, temp;
    aht.getEvent(&humi, &temp); // populate temp and humidity objects with fresh data
    temperature = temp.temperature;
    humidity = humi.relative_humidity;
    USBSerial.print("Temperature: ");
    USBSerial.print(temperature);
    USBSerial.println(" degrees C");
    USBSerial.print("Humidity: ");
    USBSerial.print(humidity);
    USBSerial.println("% rH");
}

void readResponse(WiFiClient *client){
  unsigned long timeout = millis();
  while(client->available() == 0){
    if(millis() - timeout > 5000){
      USBSerial.println(">>> Client Timeout !");
      client->stop();
      return;
    }
  }

  // Read all the lines of the reply from server and print them to Serial
  while(client->available()) {
    String line = client->readStringUntil('\r');
    USBSerial.print(line);
  }

  USBSerial.printf("\nClosing connection\n\n");
}

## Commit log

2025-08-25 Add hardware v1.2
    [SenseLora 4G LTE CAT1 Gateway V1.2.brd, SenseLora 4G LTE CAT1 Gateway V1.2.sch]
2026-04-15 Update pin definitions for LoRa module
2026-04-15 Modify LoRa pin definitions
    Updated pin definitions for LoRa module connections.

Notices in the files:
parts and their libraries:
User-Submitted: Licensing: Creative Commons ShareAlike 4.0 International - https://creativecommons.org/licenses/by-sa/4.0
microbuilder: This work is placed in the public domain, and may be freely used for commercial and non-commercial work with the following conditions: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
